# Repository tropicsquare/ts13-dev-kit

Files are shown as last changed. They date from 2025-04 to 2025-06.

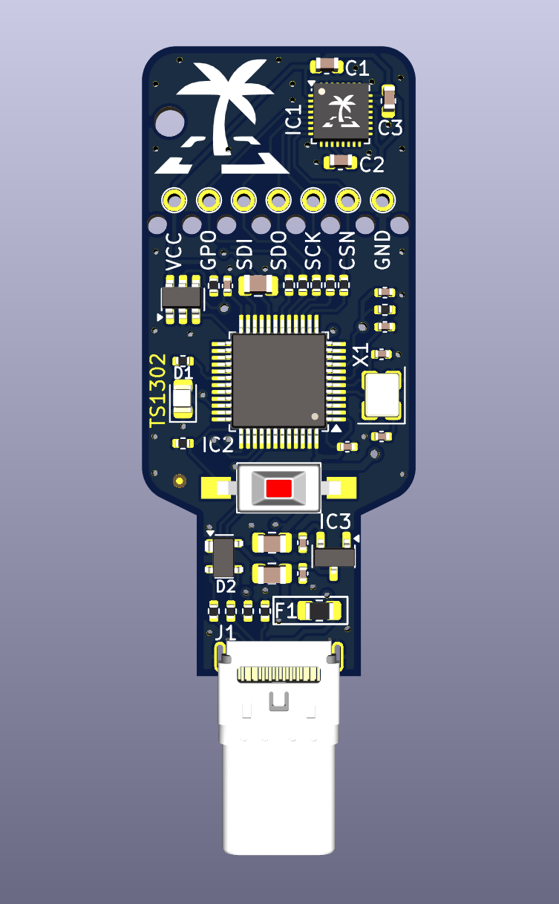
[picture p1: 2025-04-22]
img/top_assembled.png

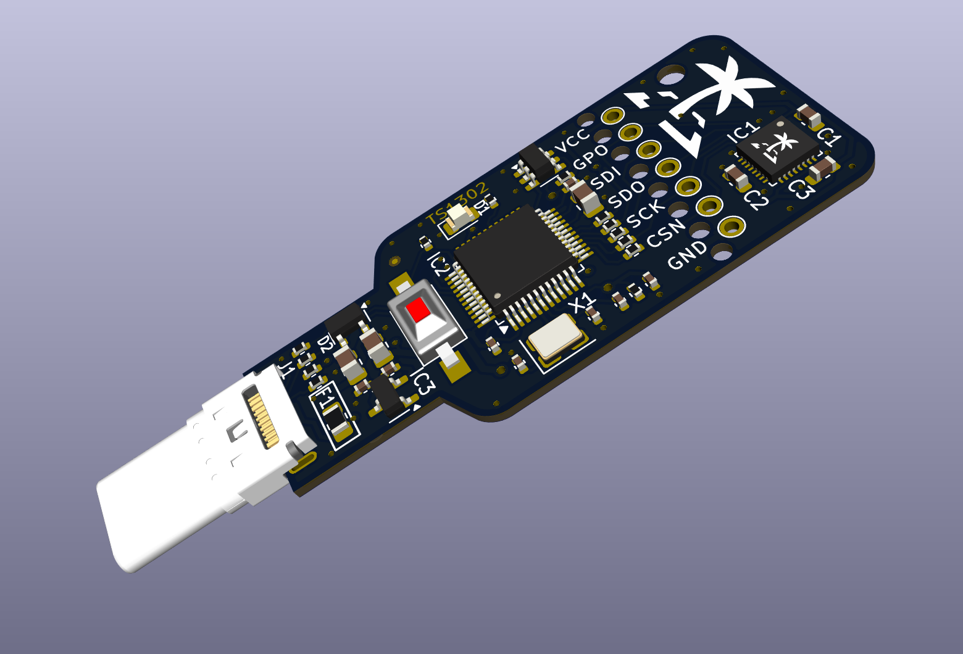
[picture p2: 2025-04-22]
img/angle.png

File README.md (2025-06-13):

# About

TS13 – TROPIC01 USB Development Kit
A KiCad-based hardware project providing a minimal development platform for the TROPIC01 chip.

The TS13 features a USB-C interface and an STM32 microcontroller acting as a USB-to-SPI converter,
enabling straightforward host communication with TROPIC01.

For firmware details and usage instructions, see the `ts-usb-dev-kit-fw.git` README.

# Project structure

`*.kicad_pro` - KiCad project file
`*.kicad_sch` - Schematic file
`*.kicad_pcb` - PCB layout file
`./out/` - Generated gerber data for PCB manufacturing
`./bom/` - Bill of materials, including order codes and interactive BOM
`./img/` - Images (PCB renders)
`*_schematics.pdf` - Exported schematic diagrams (latest version)

# Manufacturing instructions

## Assembly

There are no any special requirements for C and R components.
Where not specified the R tolerance is 5% and C 20%.

## PCB

  Number of cu layers: 2 \
  Board Thickness: 1.0 \
  Core: FR4 \
  Size: 20 x 46 mm \
  Mask: Blue \
  Silkscreen: Yes (TOP and BOTTOM)

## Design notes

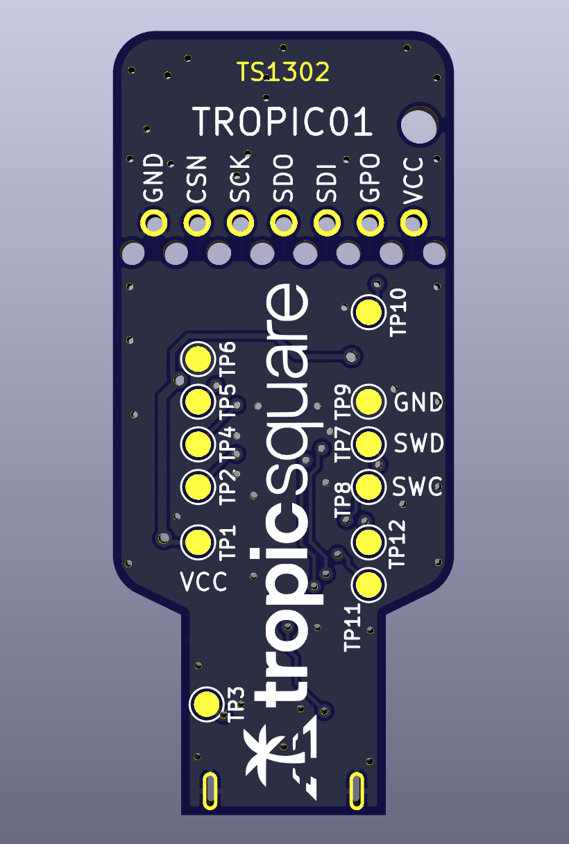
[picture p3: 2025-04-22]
img/bot.png

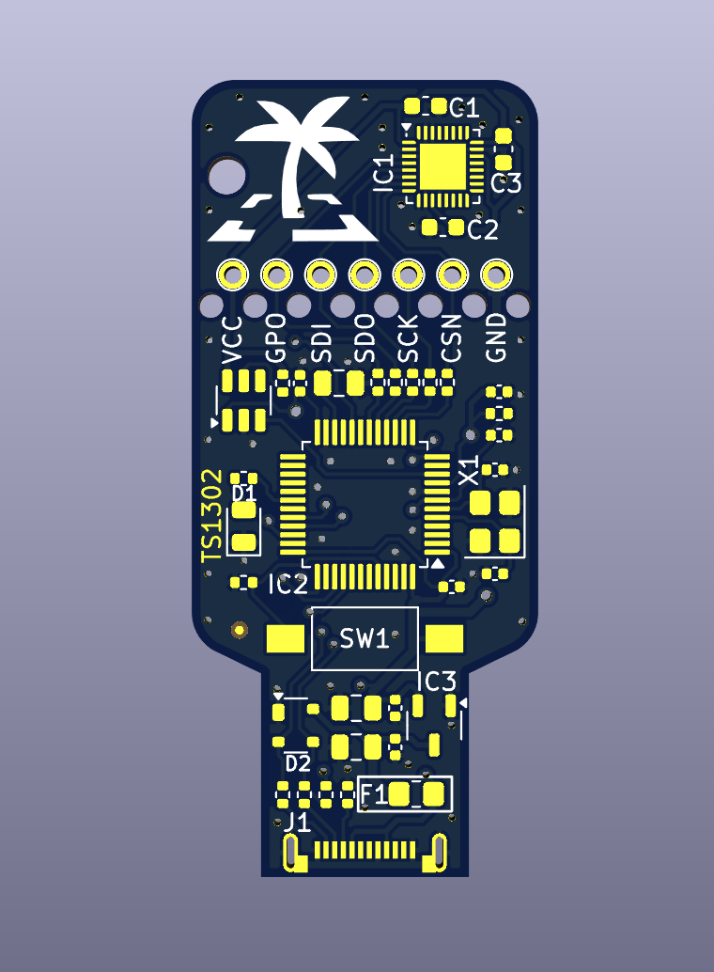
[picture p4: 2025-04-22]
img/top.png

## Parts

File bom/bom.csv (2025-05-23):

Reference | Value | Footprint | Qty | DNP | OC_MOUSER
C1,C2,C3 | 100n/603 | Capacitor_SMD:C_0603_1608Metric | 3 |  | 80-C0603104K3RAC7411
C4,C7,C14 | 4u7/16V | Capacitor_SMD:C_0805_2012Metric | 3 |  | 187-CL21A475KAQNNNE
C5,C6,C9,C13 | 100n | Capacitor_SMD:C_0402_1005Metric | 4 |  | 80-C0402C104M4RECTU
C8,C10 | 10n | Capacitor_SMD:C_0402_1005Metric | 2 |  | 80-C0402C103M4R
C11,C12 | 10p | Capacitor_SMD:C_0402_1005Metric | 2 |  | 80-C0402C100J5G
D1 | LED_R | LED_SMD:LED_0805_2012Metric | 1 |  | 710-150080RS75000
D2 | PRTR5V0U2X | Package_TO_SOT_SMD:SOT-143 | 1 |  | 771-PRTR5V0U2X-T/R
F1 | Fuse 500mA | Resistor_SMD:R_0805_2012Metric_Pad1.20x1.40mm_HandSolder | 1 |  | 594-MFU0805FF00500P1
IC1 | TROPIC01_chip | tropic01_chip:QFN-32-1EP_4x4mm_P0.4mm_EP2.65x2.65mm | 1
IC2 | STM32U535CCTx | Package_QFP:LQFP-48_7x7mm_P0.5mm | 1 |  | 511-STM32U535CCT6
IC3 | TPS7A0533PDBZR | Package_TO_SOT_SMD:SOT-23-3 | 1 |  | 595-TPS7A0533PDBZR
IC4 | TPS22917DBV | Package_TO_SOT_SMD:SOT-23-6 | 1 |  | 595-TPS22917DBVR
J1 | USB_C_Plug | _con_misc:USB_C_plug_UP20CFGFL-P12 | 1 |  | 179-UP20CFGFLP12TR
R1 | 33k | Resistor_SMD:R_0402_1005Metric | 1 |  | 603-RC0402DR-0733KL
R2,R3,R4,R5,R6,R7,R13 | 1k | Resistor_SMD:R_0402_1005Metric | 7 |  | 603-RE0402DRE071KL
R8 | 5k1 | Resistor_SMD:R_0402_1005Metric | 1 |  | 791-RGC1/16SC5101DTH
R9,R10 | 10R | Resistor_SMD:R_0402_1005Metric | 2 |  | 603-RC0402DR-0710RL
R11 | 1k5 | Resistor_SMD:R_0402_1005Metric | 1 |  | 603-RE0402DRE071K5L
R12 | 220R | Resistor_SMD:R_0402_1005Metric | 1 |  | 652-CR0402JW-221GLF
SW1 | tact switch | Button_Switch_SMD:SW_SPST_FSMSM | 1 |  | 611-PTS636SM25SMTRLF
X1 | 8MHz | Crystal:Crystal_SMD_3225-4Pin_3.2x2.5mm | 1 |  | 729-FL0800008Q

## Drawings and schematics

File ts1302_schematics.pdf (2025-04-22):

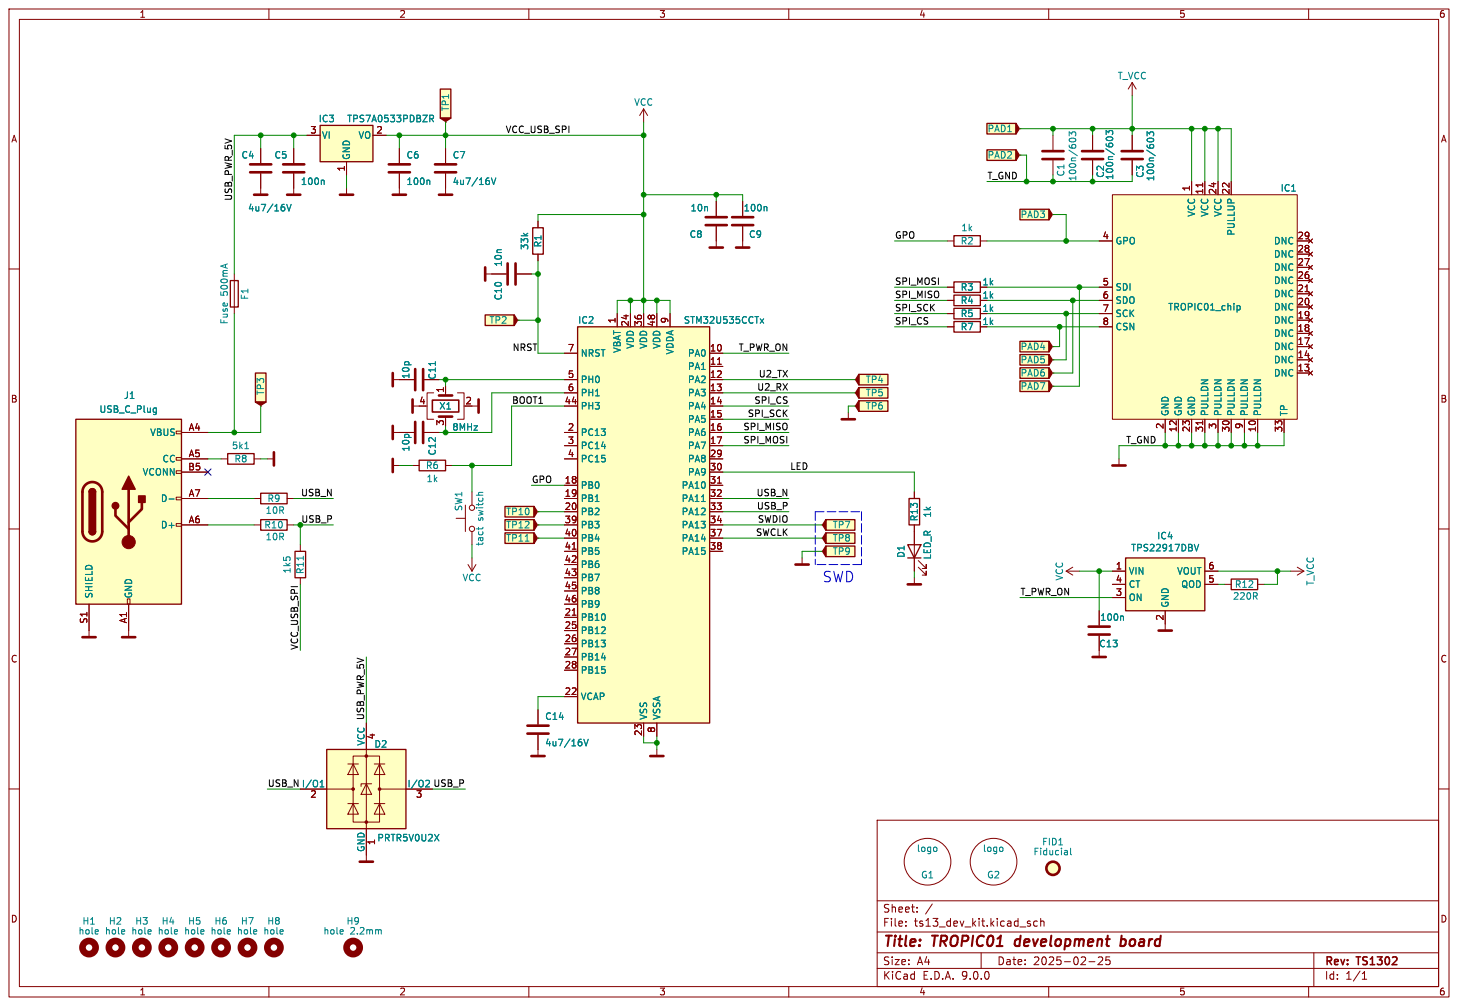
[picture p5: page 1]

1 GND 23 VCC 11 PULLDN 31 VCC 24 PULLDN

9 PULLDN 10 TP 33 DNC 29 DNC 28 DNC 27 DNC 26 DNC 21 DNC 20 DNC 19 DNC 18 DNC 17 DNC 14 DNC 13 R13 1k C9

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

1 VDD 24 VDD 36 VSS 23 VDD 48 VSSA

File: ts13_dev_kit.kicad_sch Sheet: /
Id: 1/1 Title: TROPIC01 development board

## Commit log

2025-02-06 project: Add basic project files (routed PCB)
    [ts13_dev_kit.kicad_pcb, ts13_dev_kit.kicad_sch]
2025-02-07 project: Add images and PCB cosmetic
    [ts13_dev_kit.kicad_pcb, ts13_dev_kit.kicad_sch]
2025-02-11 project: Add fabrication outputs, images and BOM
    [bom.csv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]
2025-02-19 fix: Order code for R7 was wrong
    [bom.csv, ts13_dev_kit.kicad_sch]
2025-04-22 feat: Space and cost optimization, MCU change, add button.
    [bom.csv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]
2025-04-22 feat: Add temporary TS13A version with USB-A connection
    [bom.csv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]
2025-04-22 fix: Add missing capacitor to VCAP
    [bom.csv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]
2025-05-23 fix: Change part number in BOM for SW1 (same type, different pins)
    [bom.csv, ts13_dev_kit.kicad_sch]
2025-06-13 ts13a repository cleanup.
    [bom.csv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]
